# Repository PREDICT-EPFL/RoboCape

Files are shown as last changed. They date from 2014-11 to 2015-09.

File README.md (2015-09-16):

# RoboCape

This repository is dedicated to a Beaglebone cape extension developped at EPFL in the Automatic Control Laboratory.
The idea of this platform is to allow the user to transform any mechanically actuated platform, for example a RC car or a quadcopter base, into a robotic vehicle that can be controlled by a remote server.

The repository contains all the design files of the Beaglebone cape extension.
* Schematic
* PCB layout
* Production files
* Documentation files (useful documents and datasheets)

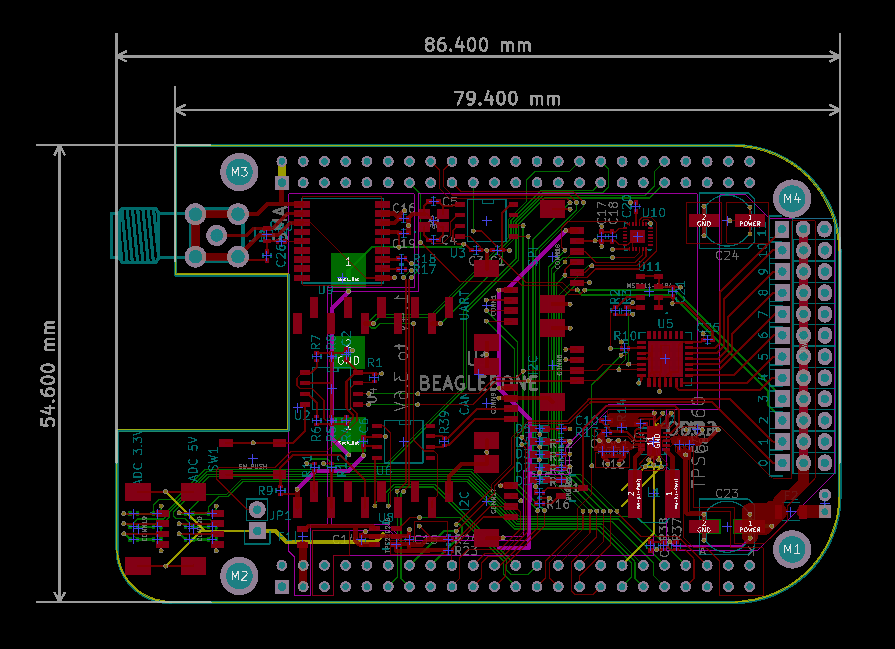
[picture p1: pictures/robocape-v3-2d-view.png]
Board Layout

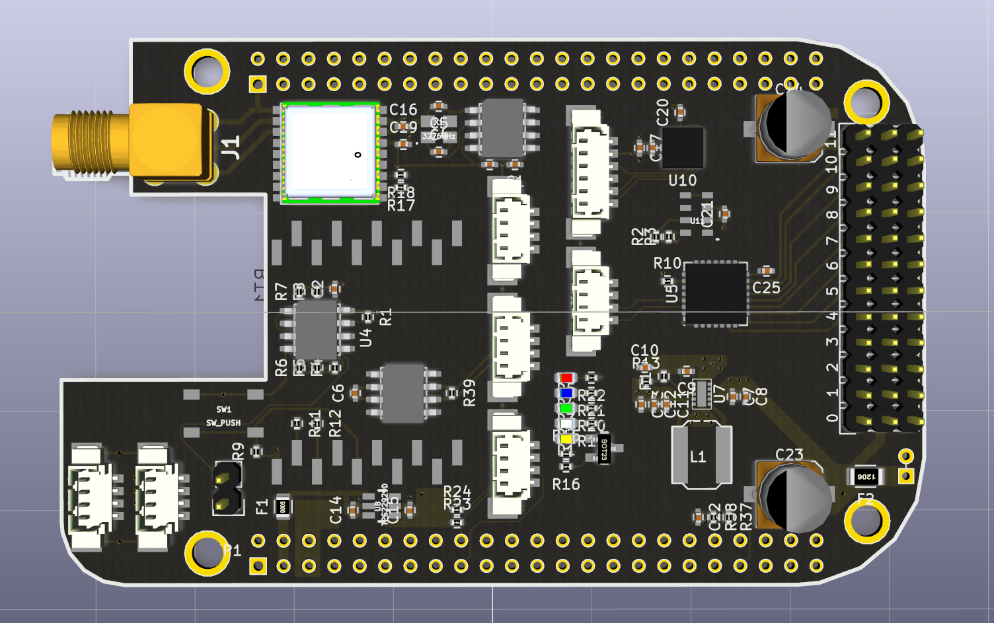
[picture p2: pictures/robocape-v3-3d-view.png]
Board 3D View


## Finished board

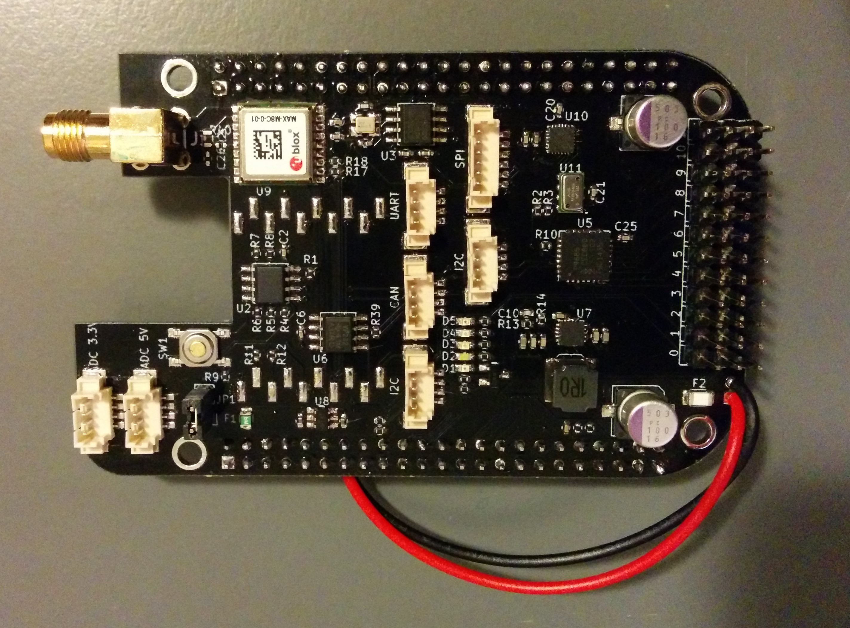
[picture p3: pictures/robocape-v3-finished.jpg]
Finished Board


## License


This project is released under the Creative Commons CC-BY-4.0 license.
See http://creativecommons.org/licenses/by/4.0/ for details.

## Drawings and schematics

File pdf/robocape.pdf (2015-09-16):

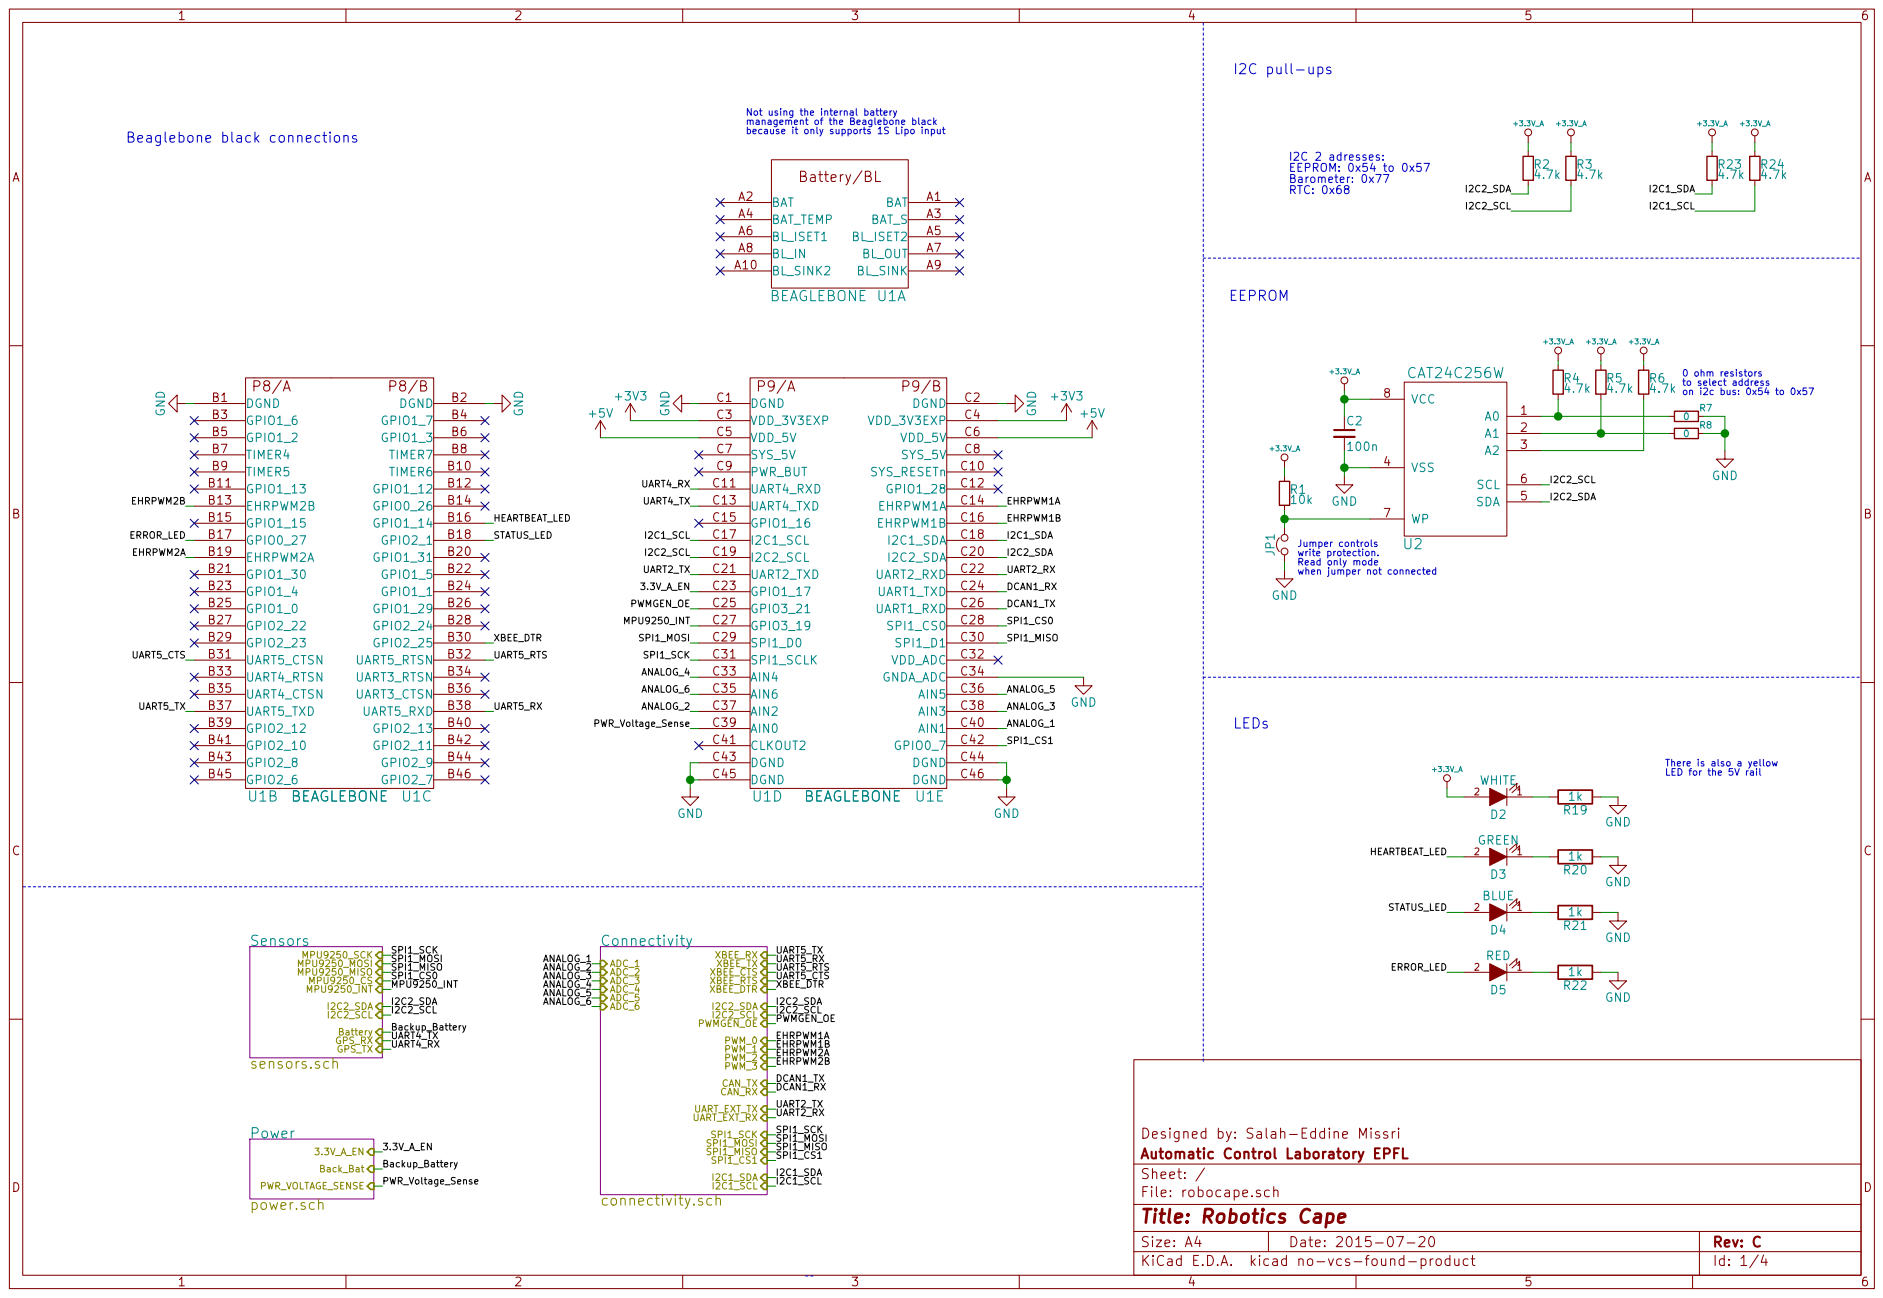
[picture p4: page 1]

0 ohm resistors
to select address on i2c bus: 0x54 to 0x57

Designed by: Salah-Eddine Missri
File: robocape.sch Sheet: / Automatic Control Laboratory EPFL

Id: 1/4 Title: Robotics Cape

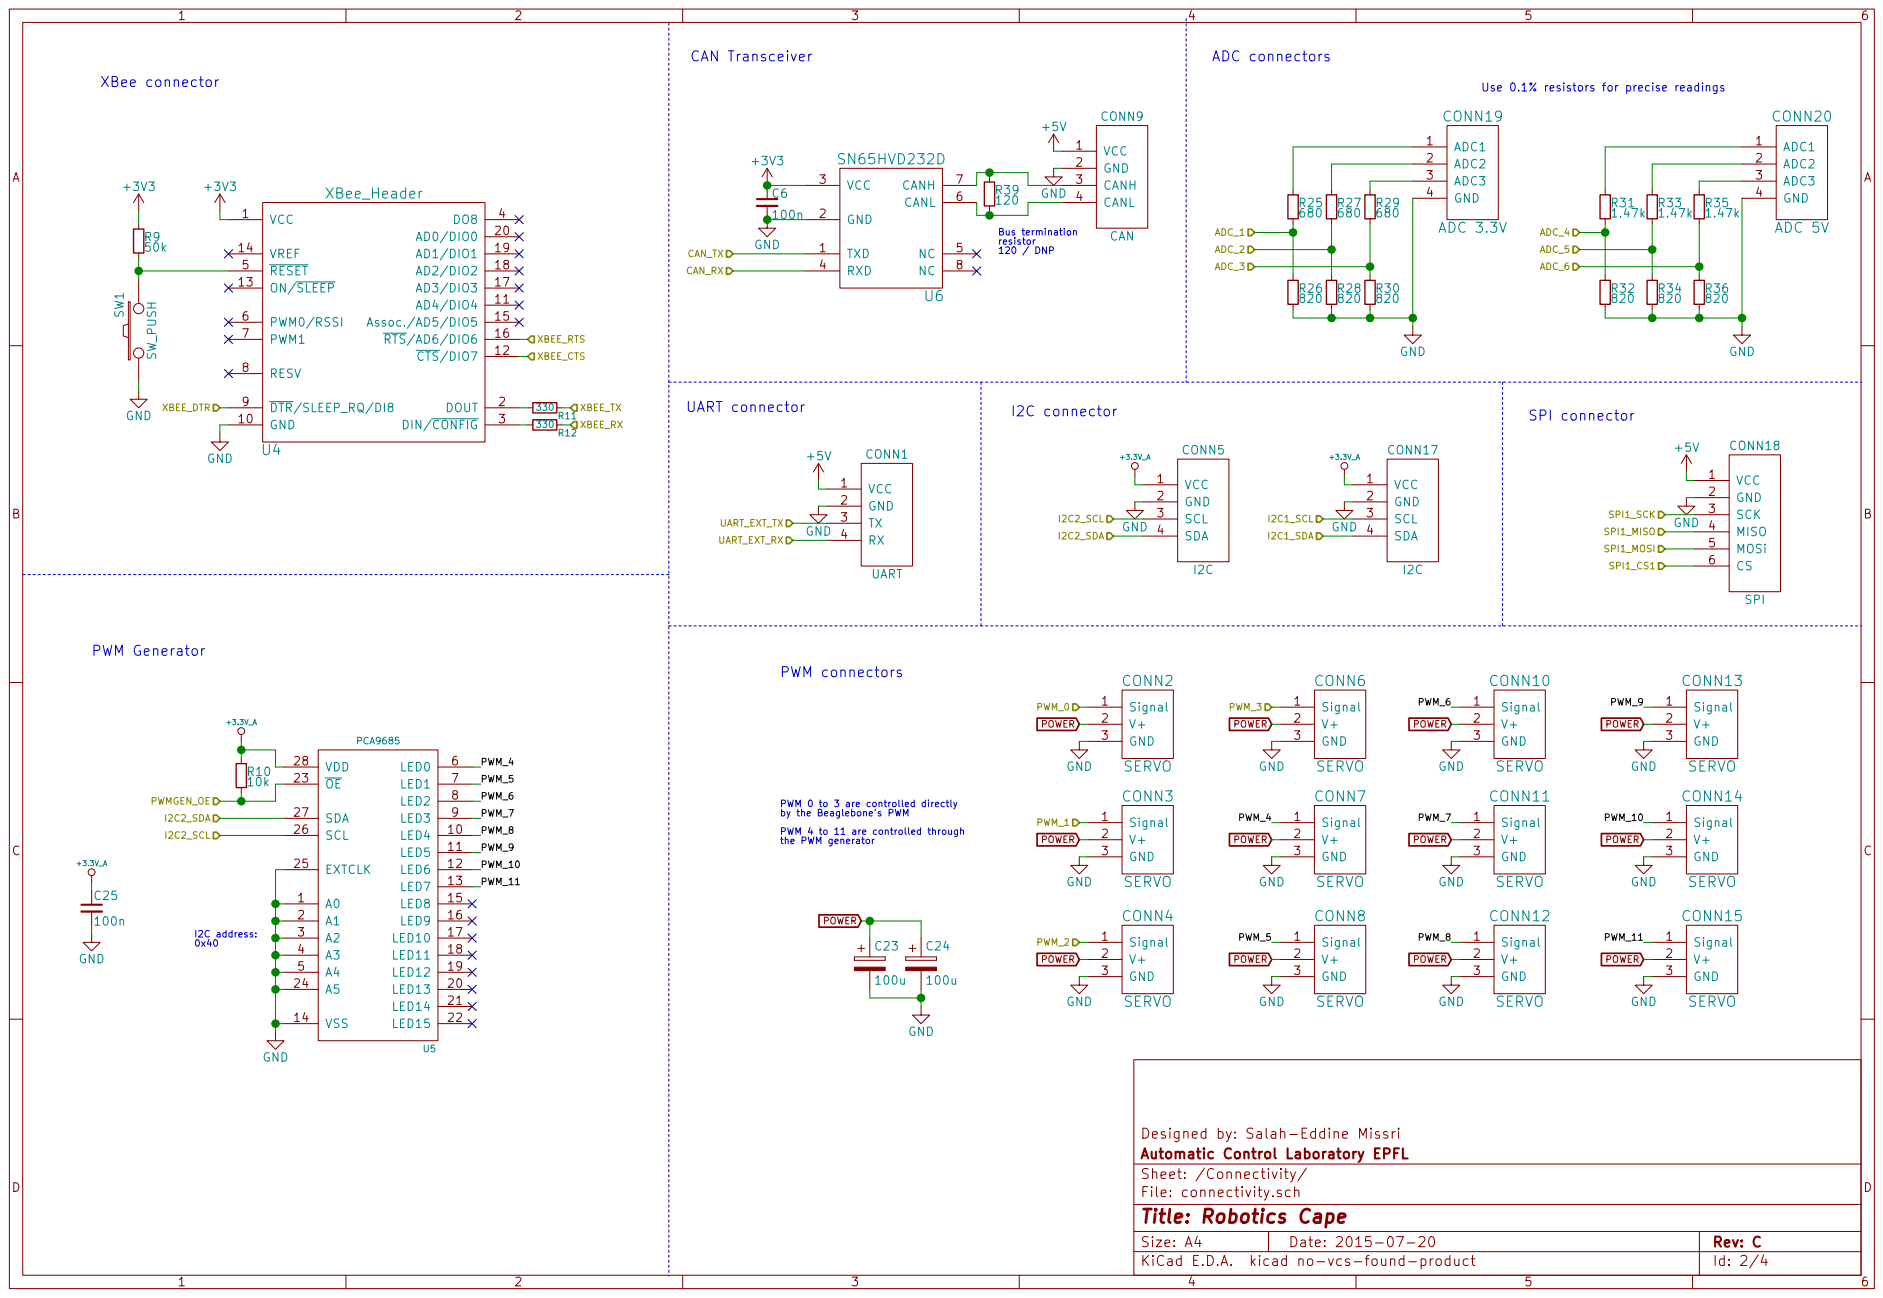
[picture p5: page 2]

1.47k Use 0.1% resistors for precise readings C23

Bus termination resistor 120 / DNP C25

PWM 0 to 3 are controlled directly by the Beaglebone's PWM

PWM 4 to 11 are controlled through

Designed by: Salah-Eddine Missri
Automatic Control Laboratory EPFL
Sheet: /Connectivity/
File: connectivity.sch
Id: 2/4 Title: Robotics Cape

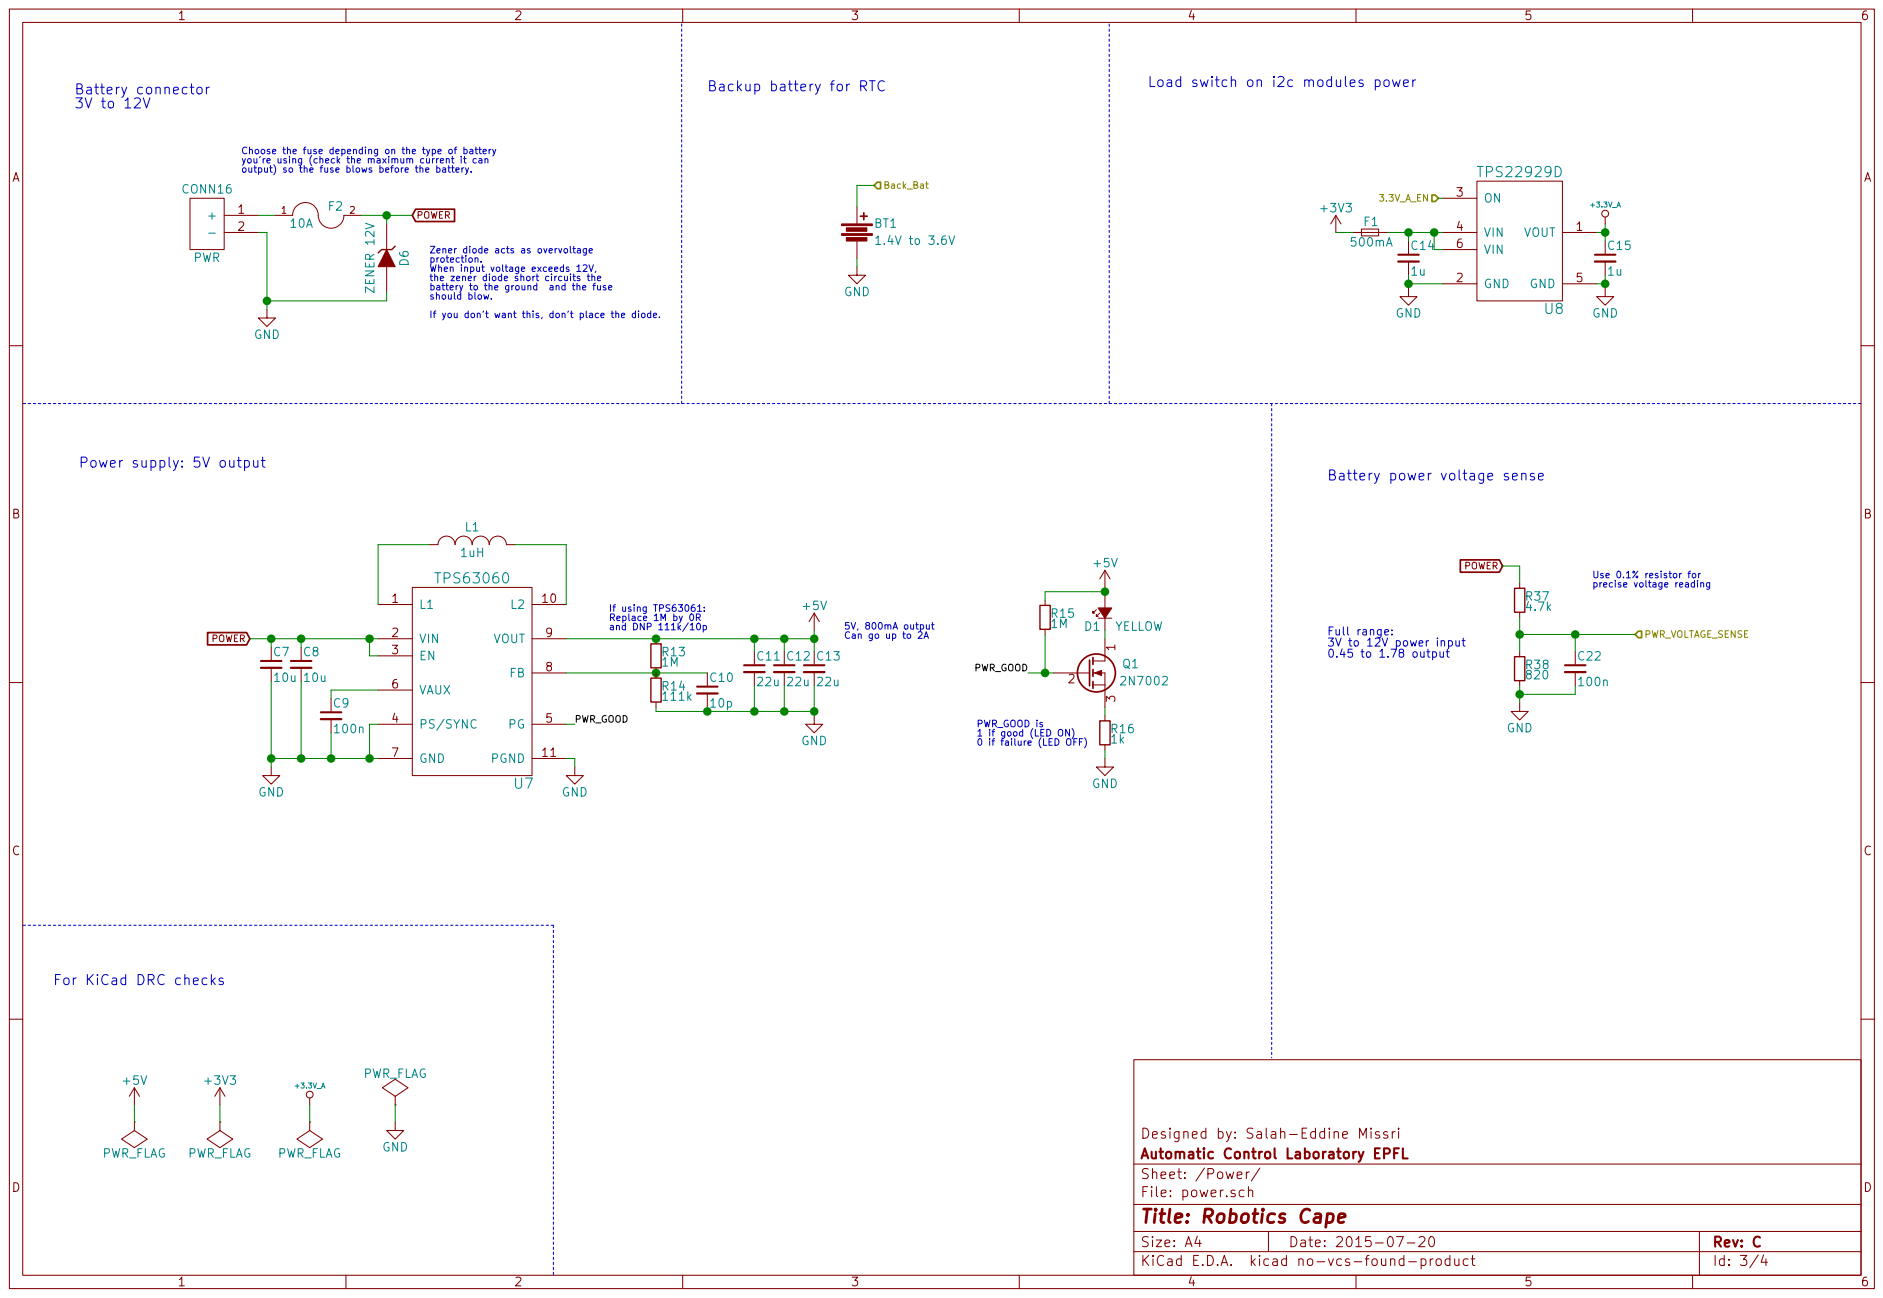
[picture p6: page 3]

Back_Bat Backup battery for RTC

Load switch on i2c modules power

If you don't want this, don't place the diode. Choose the fuse depending on the type of battery you're using (check the maximum current it can output) so the fuse blows before the battery.

the zener diode short circuits the battery to the ground and the fuse should blow.

Use 0.1% resistor for precise voltage reading Full range: 3V to 12V power input 0.45 to 1.78 output

If using TPS63061: Replace 1M by 0R

PWR_GOOD is 1 if good (LED ON) 0 if failure (LED OFF)

Designed by: Salah-Eddine Missri
File: power.sch Sheet: /Power/ Automatic Control Laboratory EPFL

Id: 3/4 Title: Robotics Cape

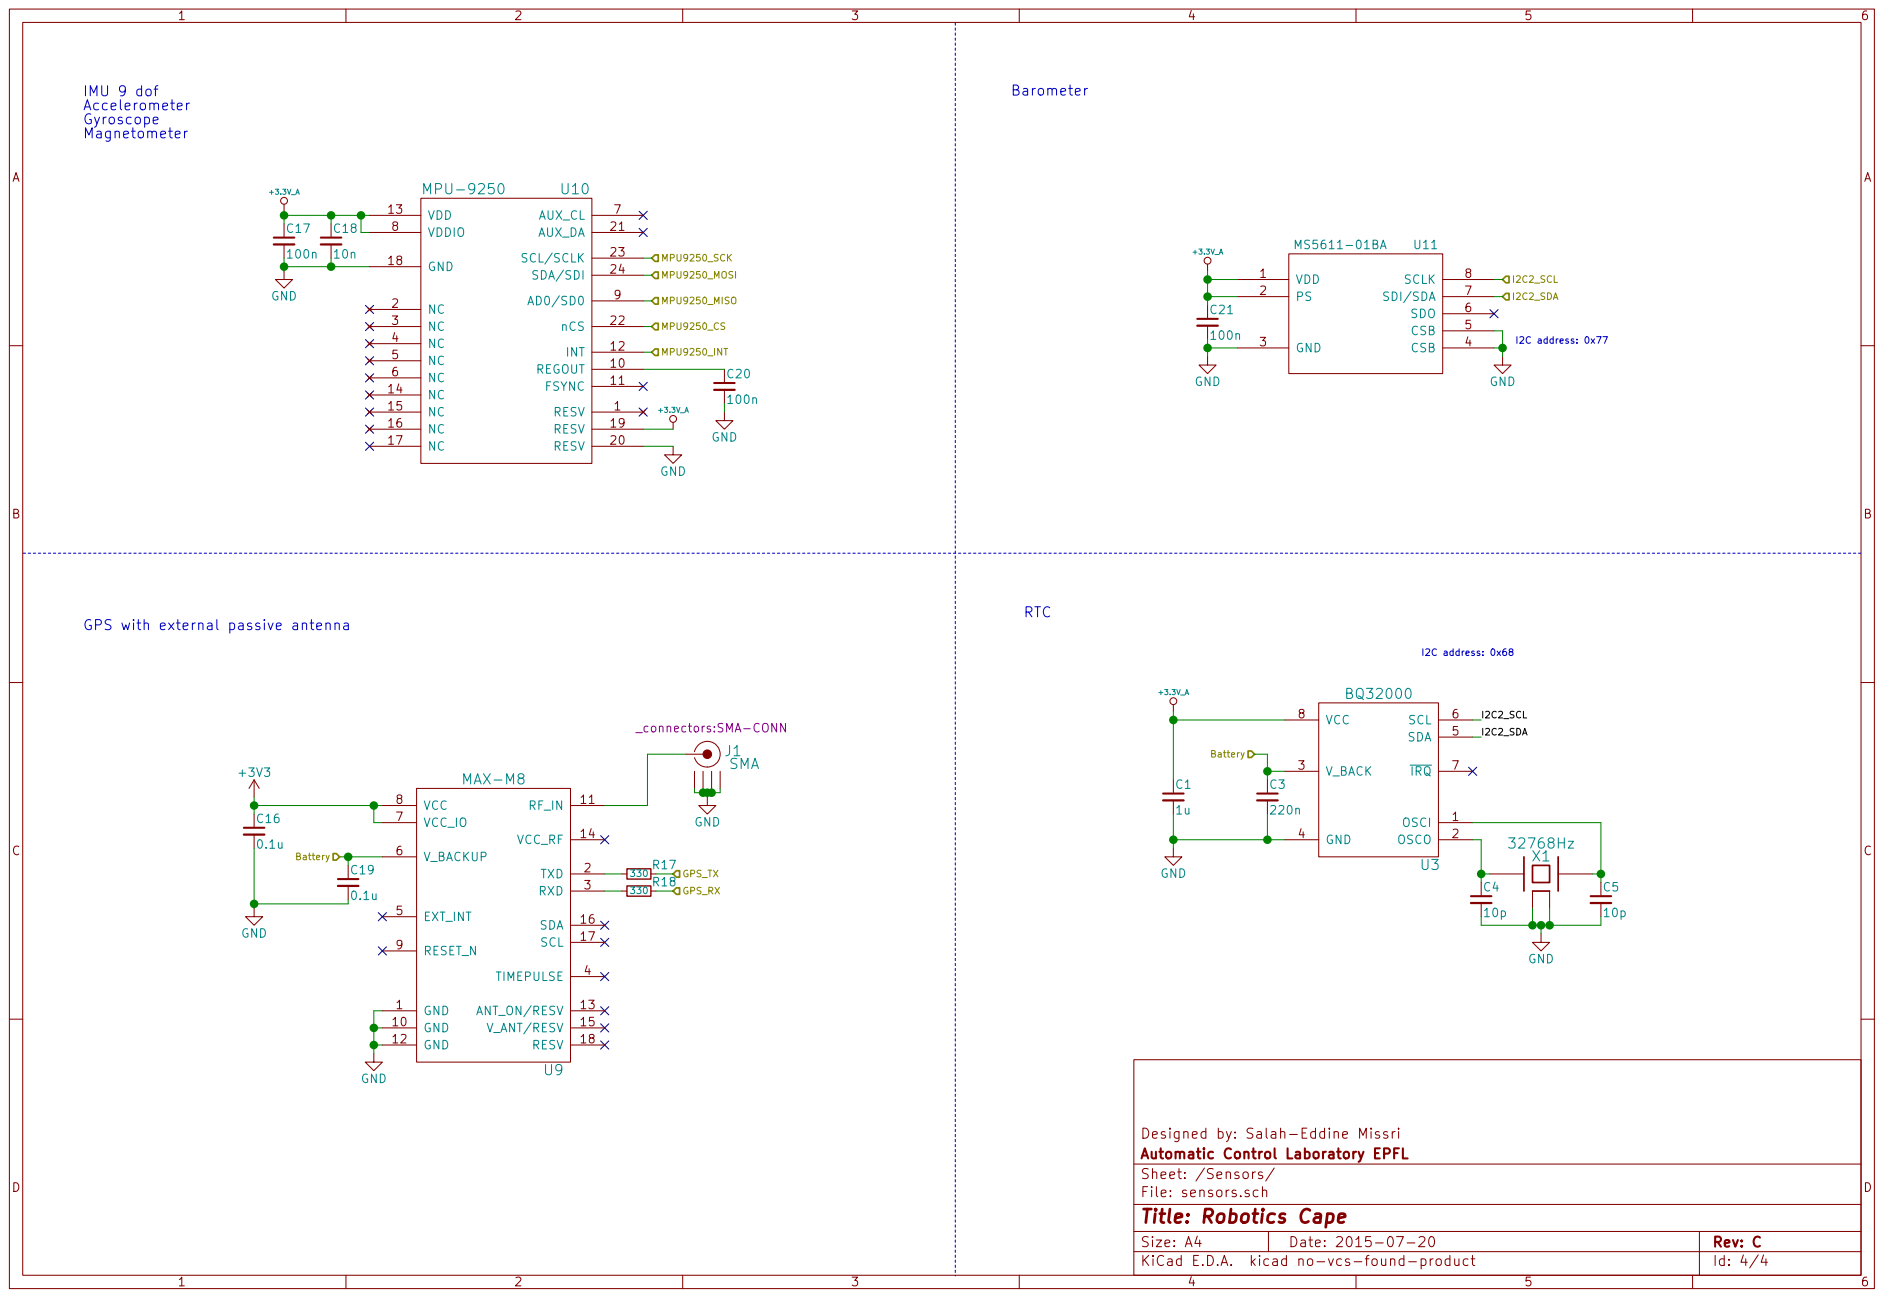
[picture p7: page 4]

IMU 9 dof Accelerometer Gyroscope

Designed by: Salah-Eddine Missri
File: sensors.sch Sheet: /Sensors/ Automatic Control Laboratory EPFL

Id: 4/4 Title: Robotics Cape

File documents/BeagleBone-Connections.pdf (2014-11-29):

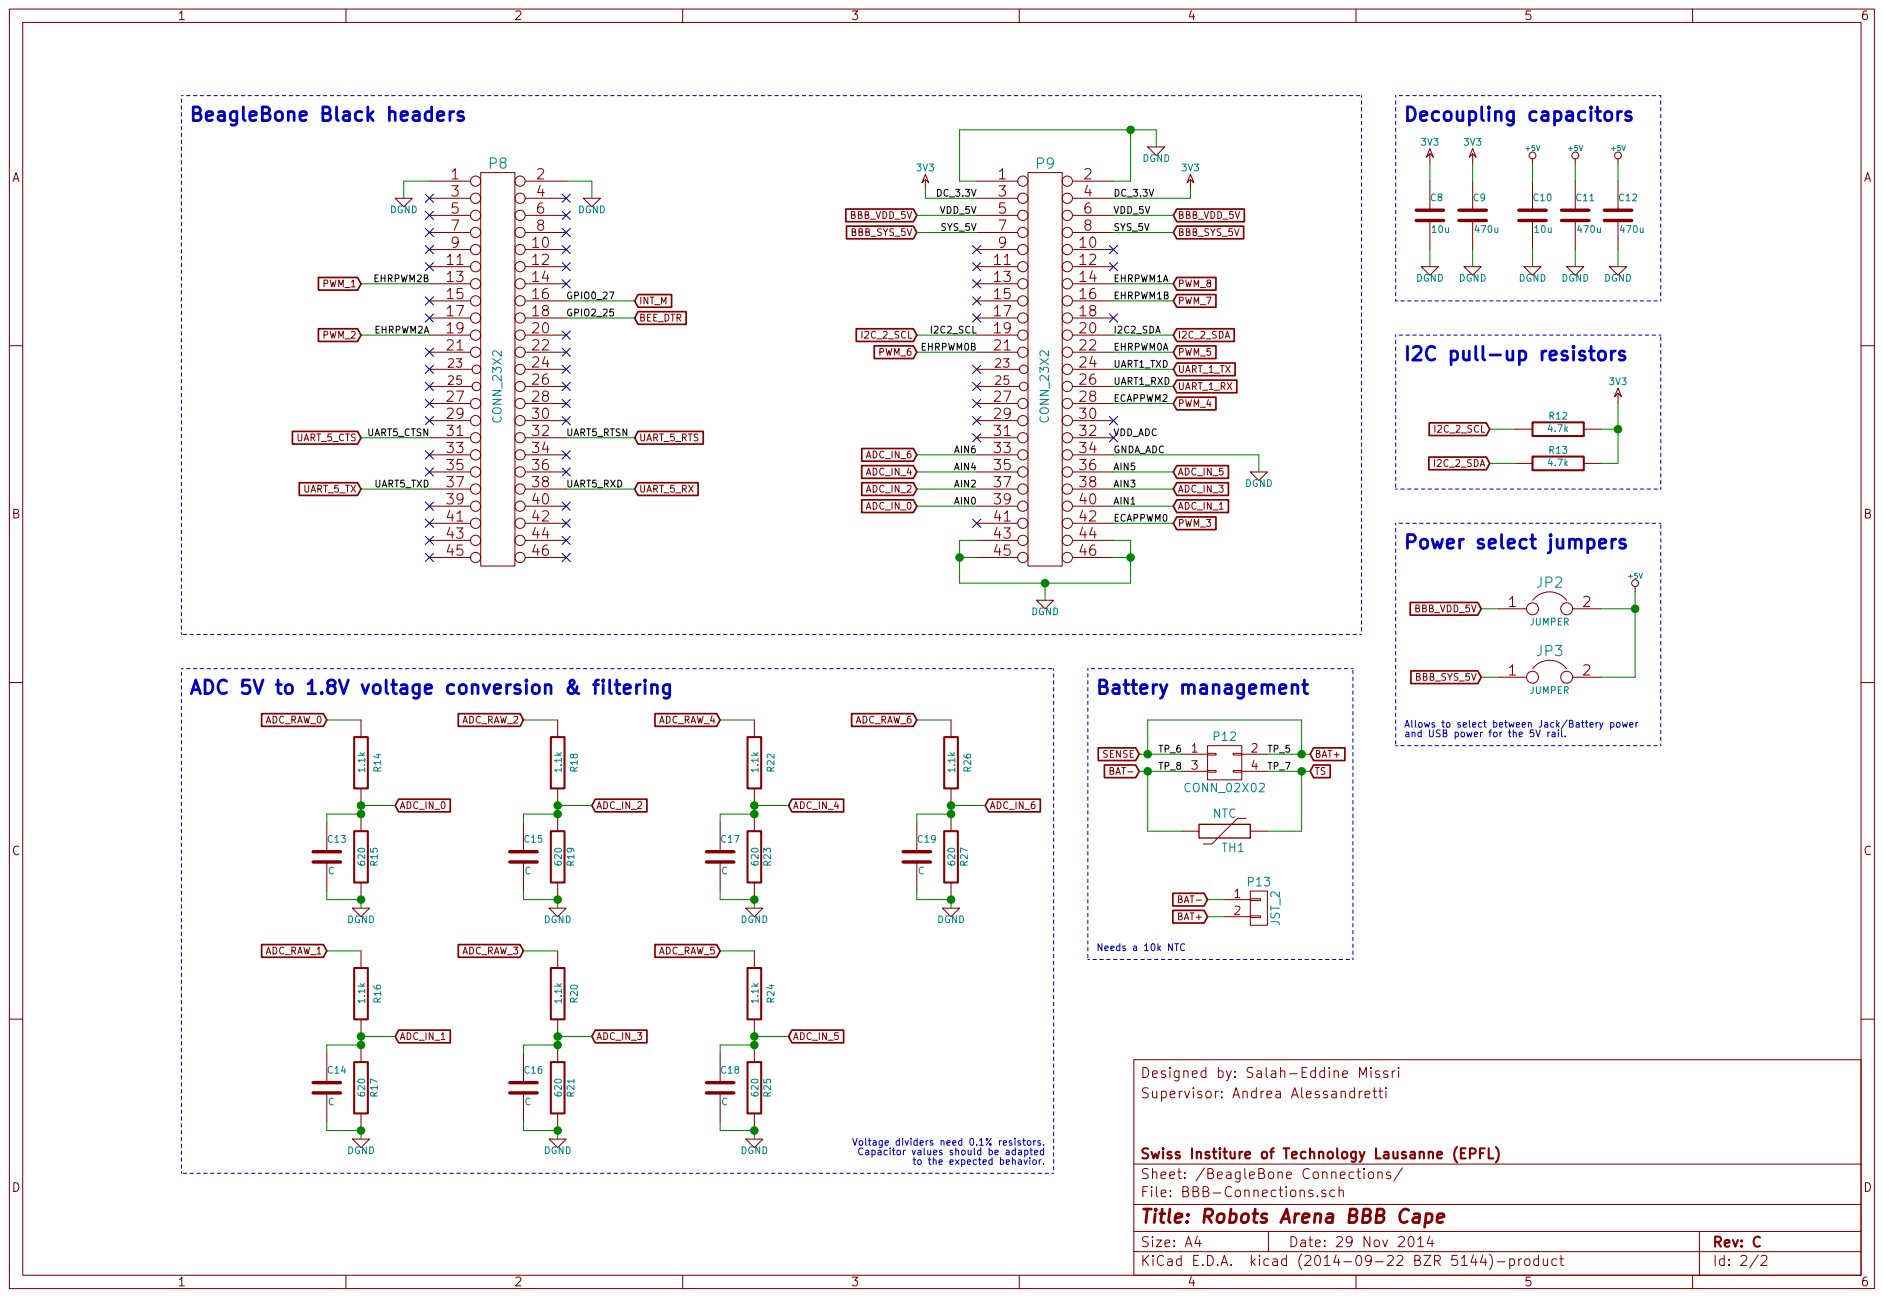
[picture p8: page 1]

JUMPER Power select jumpers

ADC_IN_5 ADC 5V to 1.8V voltage conversion & filtering

Designed by: Salah-Eddine Missri
Supervisor: Andrea Alessandretti

Voltage dividers need 0.1% resistors. Capacitor values should be adapted

Swiss Institure of Technology Lausanne (EPFL)
File: BBB-Connections.sch Sheet: /BeagleBone Connections/
Id: 2/2 Title: Robots Arena BBB Cape

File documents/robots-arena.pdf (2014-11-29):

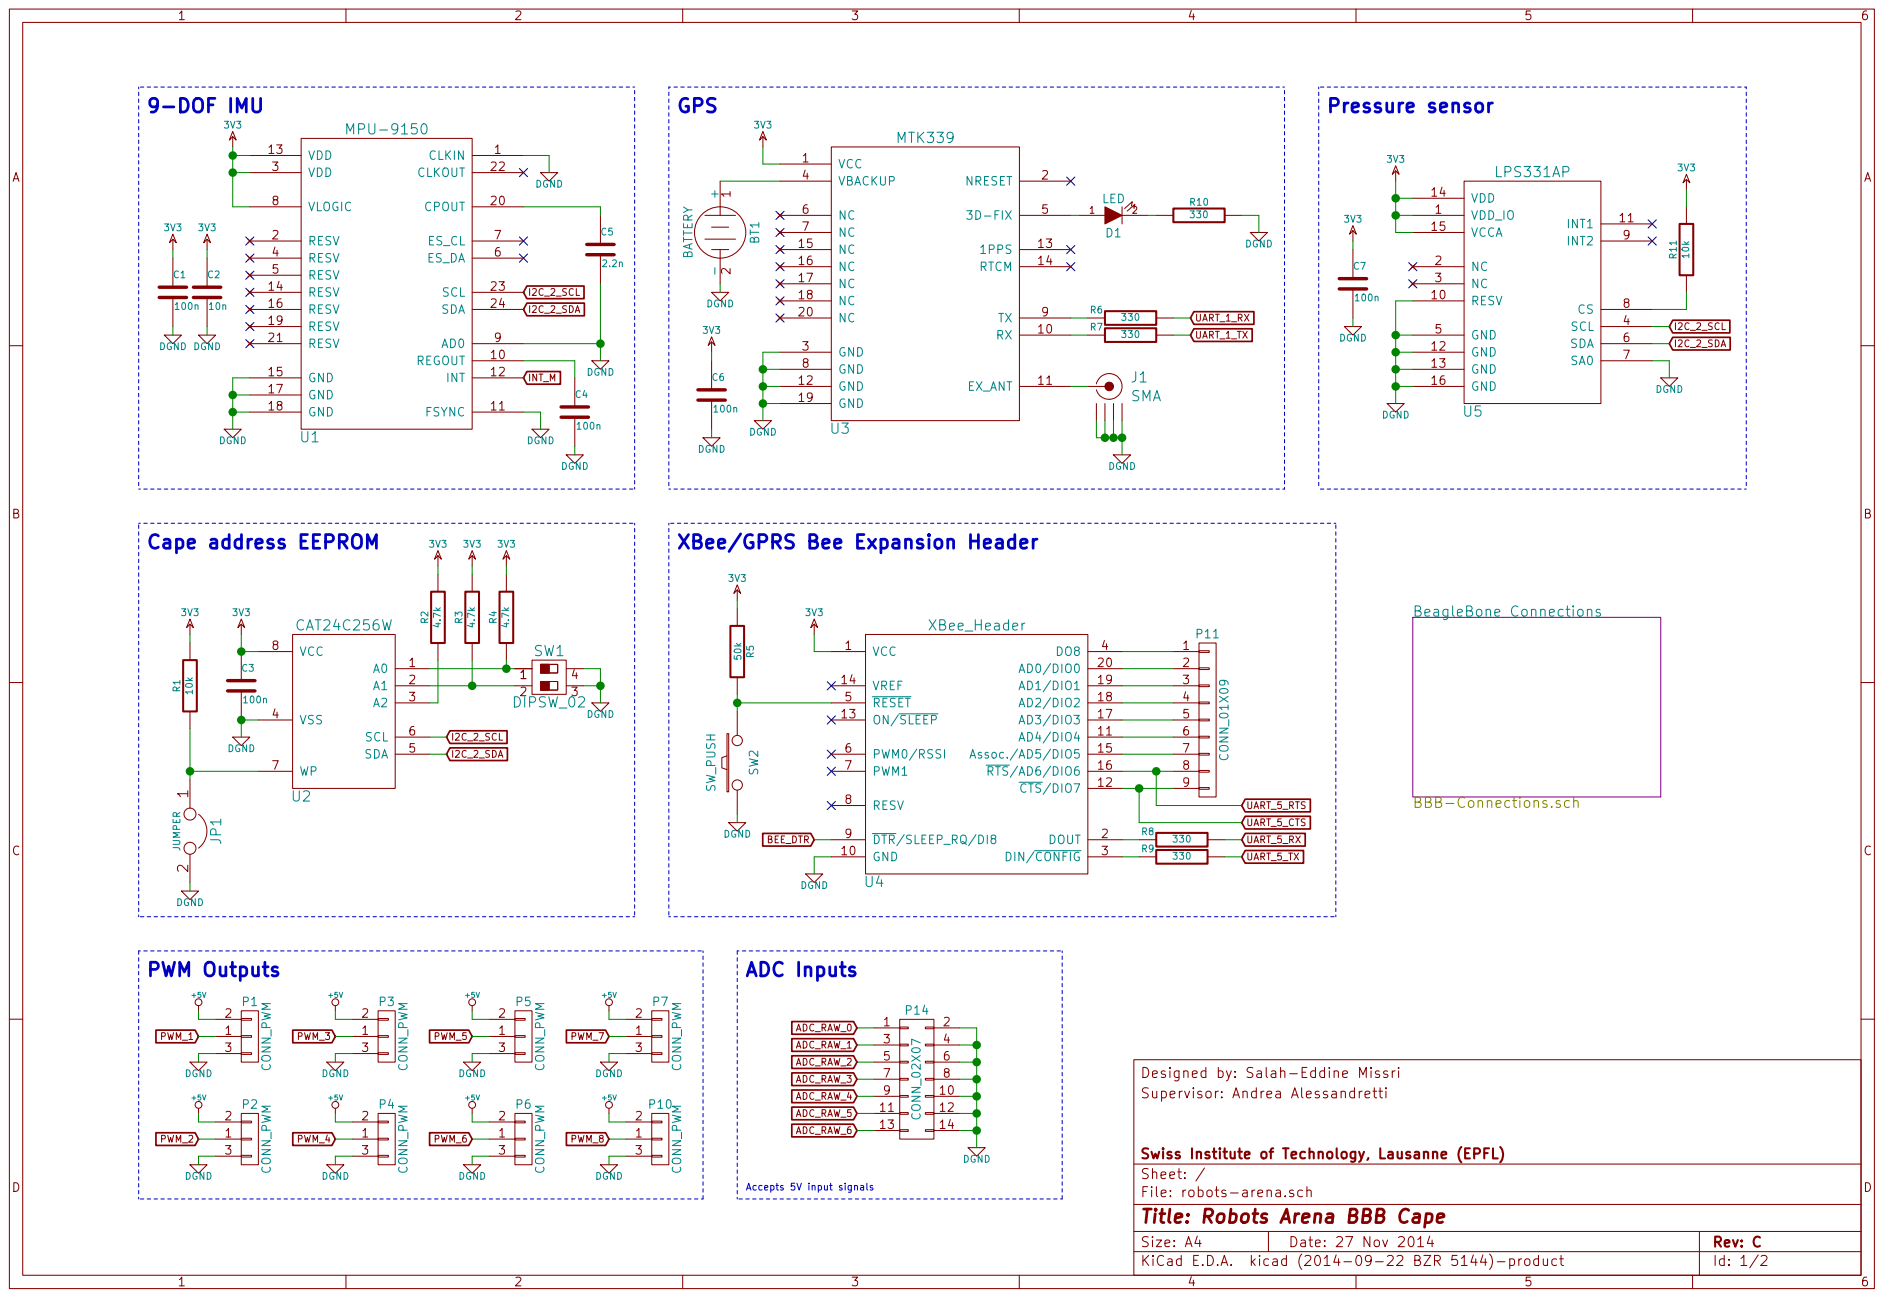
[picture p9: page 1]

9 P11 CONN_01X09 5 | UART_5_CTS UART_5_RTS UART_5_TX UART_5_RX R8

File: robots-arena.sch Sheet: / Swiss Institute of Technology, Lausanne (EPFL)

Id: 1/2 Title: Robots Arena BBB Cape

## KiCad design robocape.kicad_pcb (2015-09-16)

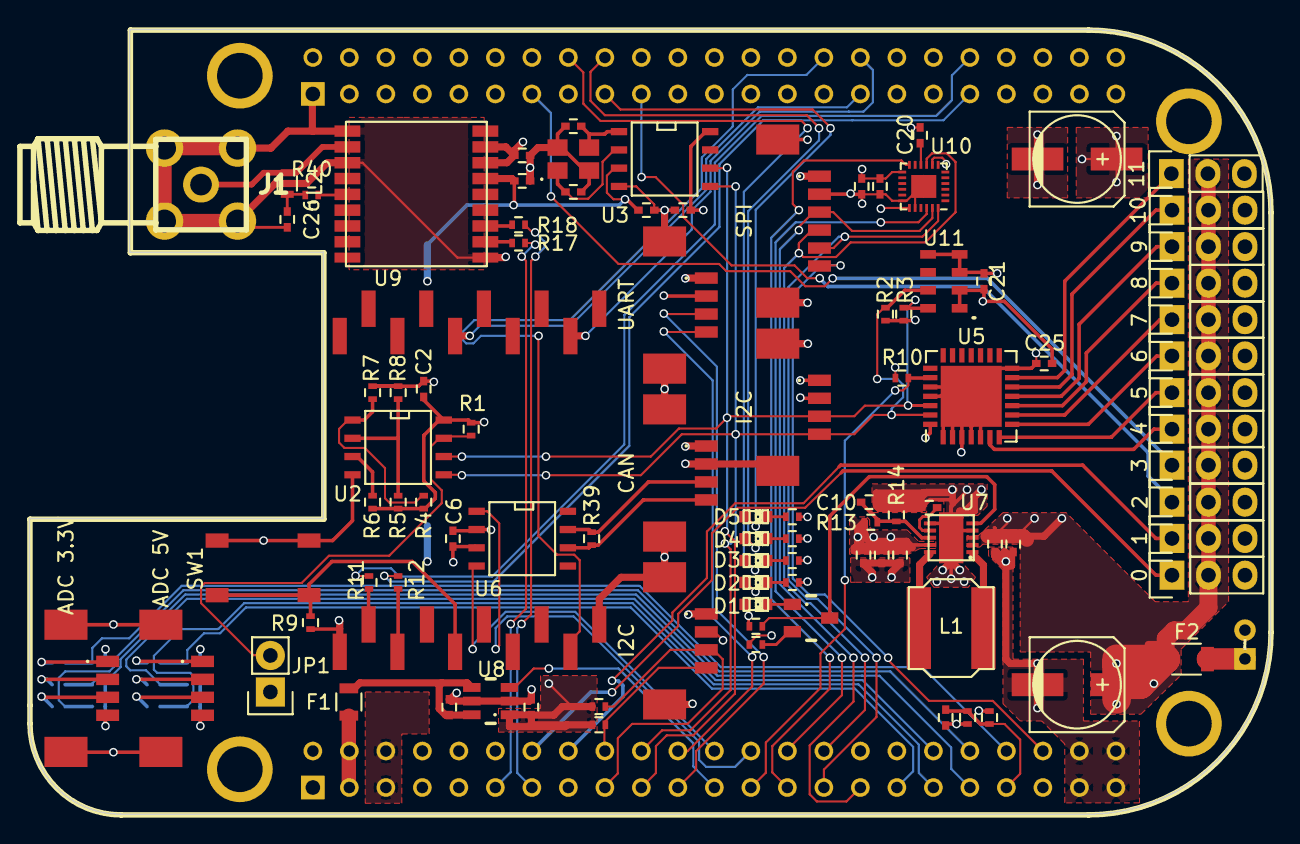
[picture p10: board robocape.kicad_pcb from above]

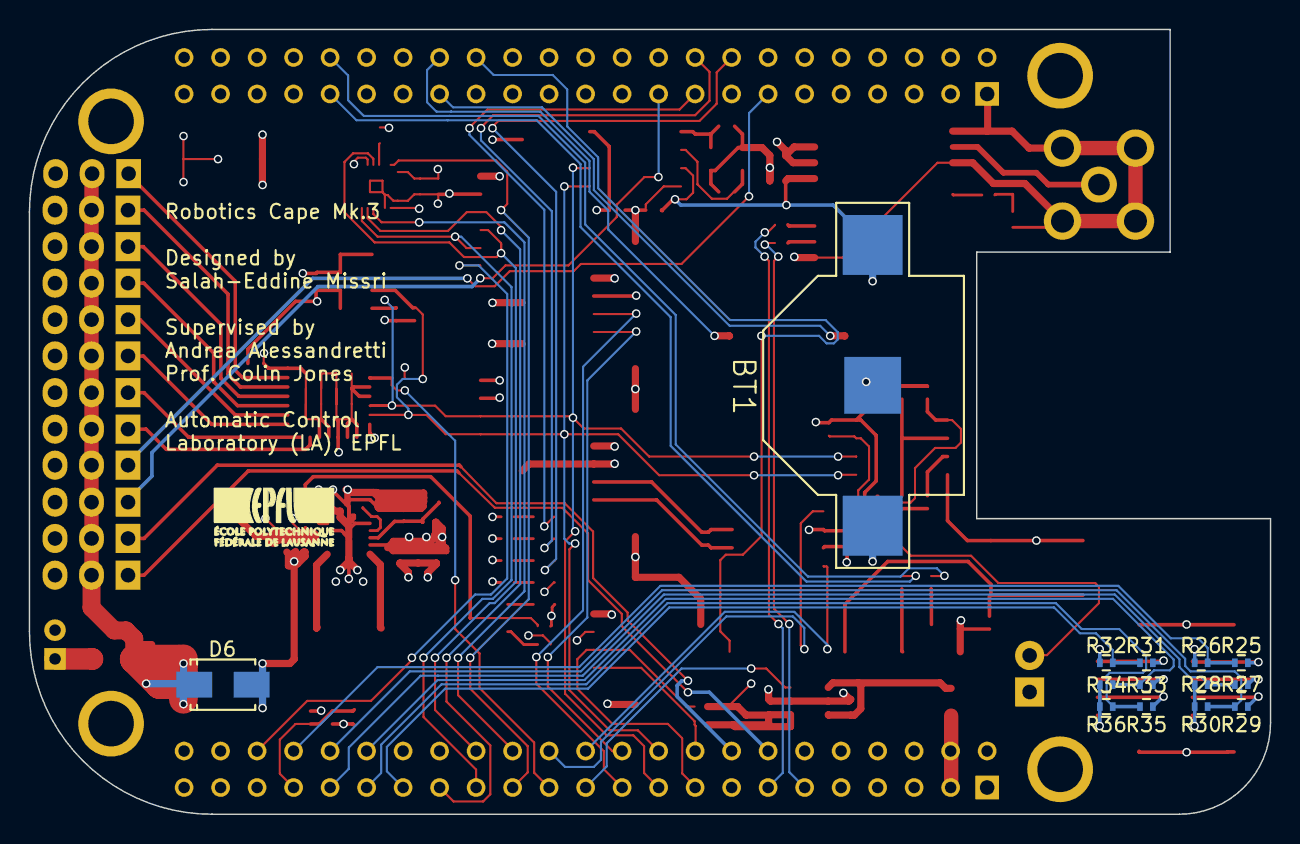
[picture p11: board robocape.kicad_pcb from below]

Board: 4 copper layers, 86.4 x 54.6 mm, 113 parts (14 on the bottom side), 87 nets.

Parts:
0, 1, 2, 3, 4, 5, 6, 7, 8, 9, 10, 11: SERVO; Pin_Header_Straight_1x03
BT1: 1.4V to 3.6V; BK-885
C1, C14, C15: 1u; C_0402
C2, C6, C9, C17, C20, C21, C22, C25: 100n; C_0402
C3: 220n; C_0402
C4, C5, C10: 10p; C_0402
C7, C8: 10u; C_0402
C11, C12, C13: 22u; C_0402
C16, C19: 0.1u; C_0402
C18: 10n; C_0402
C23, C24: 100u; c_elec_6.3x7.7
C26: C; C_0402
CONN1: UART; _Molex-PicoBlade-SMD-4
CONN5, CONN17: I2C; _Molex-PicoBlade-SMD-4
CONN9: CAN; _Molex-PicoBlade-SMD-4
CONN16: PWR; _Pin2mm_2
CONN18: SPI; _Molex-PicoBlade-SMD-6
CONN19: ADC 3.3V; _Molex-PicoBlade-SMD-4
CONN20: ADC 5V; _Molex-PicoBlade-SMD-4
D1: YELLOW; LED-0603
D2: WHITE; LED-0603
D3: GREEN; LED-0603
D4: BLUE; LED-0603
D5: RED; LED-0603
D6: ZENER 12V; Diode-SMA_Standard
F1: 500mA; R_0805
F2: 10A; R_1206
J1: SMA; SMA-CONN
JP1: Jumper_NC_Small; Pin_Header_Straight_1x02
L1: 1uH; Laird_TYS6045
L2: L; R_0603
Q1: 2N7002; _SOT23-3
R1, R10: 10k; R_0402
R2, R3, R4, R5, R6, R23, R24, R37: 4.7k; R_0402
R7, R8: 0; R_0402
R9: 50k; R_0402
R11, R12, R17, R18: 330; R_0402
R13, R15: 1M; R_0402
R14: 111k; R_0402
R16, R19, R20, R21, R22: 1k; R_0402
R25, R27, R29: 680; R_0402
R26, R28, R30, R32, R34, R36, R38: 820; R_0402
R31, R33, R35: 1.47k; R_0402
R39: 120; R_0402
R40: 10; R_0402
SW1: SW_PUSH; _PTS525SK15-SMT-Pushbutton
U1: BEAGLEBONE
U2: CAT24C256W; SOIC-8-N
U3: BQ32000; SOIC-8-N
U4: XBee_Header; Xbee_Header_SMD
U5: PCA9685; QFN-28-1EP_6x6mm_Pitch0.65mm
U6: SN65HVD232D; SOIC-8-N
U7: TPS63060; SON-10
U8: TPS22929D; _TSOT23-6
U9: MAX-M8
U10: MPU-9250; QFN-24-1EP_3x3mm_Pitch0.4mm
U11: MS5611-01BA; _MS5611-01BA
X1: 32768Hz; _TSX-3225-SMD-XTAL

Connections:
+3.3V_A: C1.1, C2.1, C15.1, C17.1, C18.1, C21.1, C25.1, CONN5.1, CONN17.1, D2.2, R1.1, R2.1, R3.1, R4.1, R5.1, R6.1, R10.1, R23.1, R24.1, U2.8, U3.8, U5.28, U8.1, U10.8, U10.13, U10.19, U11.1, U11.2
+3V3: C6.1, C16.1, F1.1, R9.1, U1.C3, U1.C4, U4.1, U6.3, U9.7, U9.8
+5V: C11.1, C12.1, C13.1, CONN1.1, CONN9.1, CONN18.1, D1.2, R13.1, R15.1, U1.C5, U1.C6, U7.9
/Connectivity/ADC_1: R25.2, R26.1, U1.C40
/Connectivity/ADC_2: R27.2, R28.1, U1.C37
/Connectivity/ADC_3: R29.2, R30.1, U1.C38
/Connectivity/ADC_4: R31.2, R32.1, U1.C33
/Connectivity/ADC_5: R33.2, R34.1, U1.C36
/Connectivity/ADC_6: R35.2, R36.1, U1.C35
/Connectivity/CAN_RX: U1.C24, U6.4
/Connectivity/CAN_TX: U1.C26, U6.1
/Connectivity/I2C1_SCL: CONN17.3, R24.2, U1.C17
/Connectivity/I2C1_SDA: CONN17.4, R23.2, U1.C18
/Connectivity/I2C2_SCL: CONN5.3, R3.2, U1.C19, U2.6, U3.6, U5.26, U11.8
/Connectivity/I2C2_SDA: CONN5.4, R2.2, U1.C20, U2.5, U3.5, U5.27, U11.7
/Connectivity/PWMGEN_OE: R10.2, U1.C25, U5.23
/Connectivity/PWM_0: 0.1, U1.C14
/Connectivity/PWM_1: 1.1, U1.C16
/Connectivity/PWM_2: 2.1, U1.B19
/Connectivity/PWM_3: 3.1, U1.B13
/Connectivity/PWM_4: 4.1, U5.6
/Connectivity/PWM_5: 5.1, U5.7
/Connectivity/PWM_6: 6.1, U5.8
/Connectivity/PWM_7: 7.1, U5.9
/Connectivity/PWM_8: 8.1, U5.10
/Connectivity/PWM_9: 9.1, U5.11
/Connectivity/PWM_10: 10.1, U5.12
/Connectivity/PWM_11: 11.1, U5.13
/Connectivity/SPI1_CS1: CONN18.6, U1.C42
/Connectivity/UART_EXT_RX: CONN1.4, U1.C22
/Connectivity/UART_EXT_TX: CONN1.3, U1.C21
/Connectivity/XBEE_CTS: U1.B32, U4.12
/Connectivity/XBEE_DTR: U1.B30, U4.9
/Connectivity/XBEE_RTS: U1.B31, U4.16
/Connectivity/XBEE_RX: R12.1, U1.B37
/Connectivity/XBEE_TX: R11.1, U1.B38
/ERROR_LED: D5.2, U1.B17
/HEARTBEAT_LED: D3.2, U1.B16
/Power/3.3V_A_EN: U1.C23, U8.3
/Power/Back_Bat: BT1.1, C3.1, C19.1, U3.3, U9.6
/Power/PWR_GOOD: Q1.2, R15.2, U7.5
/Power/PWR_VOLTAGE_SENSE: C22.1, R37.2, R38.1, U1.C39
/STATUS_LED: D4.2, U1.B18
/Sensors/GPS_RX: R18.1, U1.C13
/Sensors/GPS_TX: R17.1, U1.C11
/Sensors/MPU9250_CS: U1.C28, U10.22
/Sensors/MPU9250_INT: U1.C27, U10.12
/Sensors/MPU9250_MISO: CONN18.4, U1.C30, U10.9
/Sensors/MPU9250_MOSI: CONN18.5, U1.C29, U10.24
/Sensors/MPU9250_SCK: CONN18.3, U1.C31, U10.23
GND: 0.3, 1.3, 2.3, 3.3, 4.3, 5.3, 6.3, 7.3, 8.3, 9.3, 10.3, 11.3, BT1.2, C1.2, C2.2, C3.2, C4.2, C5.2, C6.2, C7.2, C8.2, C9.2, C10.2, C11.2, C12.2, C13.2, C14.2, C15.2, C16.2, C17.2, C18.2, C19.2, C20.2, C21.2, C22.2, C23.2, C24.2, C25.2, C26.2, CONN1.2, CONN1.MECH, CONN5.2, CONN5.MECH, CONN9.2, CONN9.MECH, CONN16.2, CONN17.2, CONN17.MECH, CONN18.2, CONN18.MECH, CONN19.4, CONN19.MECH, CONN20.4, CONN20.MECH, D6.2, J1.2, J1.3, J1.4, J1.5, JP1.1, R7.2, R8.2, R14.2, R16.2, R19.1, R20.1, R21.1, R22.1, R26.2, R28.2, R30.2, R32.2, R34.2, R36.2, R38.2, SW1.1, U1.B1, U1.B2, U1.C1, U1.C2, U1.C34, U1.C43, U1.C44, U1.C45, U1.C46, U2.4, U3.4, U4.10, U5.1, U5.2, U5.3, U5.4, U5.5, U5.14, U5.24, U5.25, U5.29, U6.2, U7.4, U7.7, U7.11, U8.2, U8.5, U9.1, U9.10, U9.12, U10.18, U10.20, U10.25, U11.3, U11.4, U11.5, X1.2, X1.4
unnamed: C4.1, U3.2, X1.1
unnamed: C5.1, U3.1, X1.3
unnamed: C9.1, U7.6
unnamed: C10.1, R13.2, R14.1, U7.8
unnamed: C14.1, F1.2, U8.4, U8.6
unnamed: C20.1, U10.10
unnamed: C26.1, L2.2, R40.1
unnamed: CONN9.3, R39.1, U6.7
unnamed: CONN9.4, R39.2, U6.6
unnamed: CONN16.1, F2.1
unnamed: CONN19.1, R25.1
unnamed: CONN19.2, R27.1
unnamed: CONN19.3, R29.1
unnamed: CONN20.1, R31.1
unnamed: CONN20.2, R33.1
unnamed: CONN20.3, R35.1
unnamed: D1.1, Q1.1
unnamed: D2.1, R19.2
unnamed: D3.1, R20.2
unnamed: D4.1, R21.2
unnamed: D5.1, R22.2
unnamed: J1.1, L2.1, U9.11
unnamed: JP1.2, R1.2, U2.7
unnamed: L1.1, U7.1
unnamed: L1.2, U7.10
unnamed: Q1.3, R16.1
unnamed: R4.2, R7.1, U2.1
unnamed: R5.2, R8.1, U2.2
unnamed: R6.2, U2.3
unnamed: R9.2, SW1.2, U4.5
unnamed: R11.2, U4.2
unnamed: R12.2, U4.3
unnamed: R17.2, U9.2
unnamed: R18.2, U9.3
unnamed: R40.2, U9.14
POWER: 0.2, 1.2, 2.2, 3.2, 4.2, 5.2, 6.2, 7.2, 8.2, 9.2, 10.2, 11.2, C7.1, C8.1, C23.1, C24.1, D6.1, F2.2, R37.1, U7.2, U7.3

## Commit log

2014-11-10 v0.1 of the cape, tested and working
    [BOM_v0.1.xlsx, RA-BBB-Connections.sch, RA-BackupConns.sch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]
2014-11-22 organisation restructuration
    [BOM_v0.1.xlsx, RA-BBB-Connections.sch, RA-BackupConns.sch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]
2014-11-23 restructuration of components & schematic
    [BBB-Connections.sch, RA-BBB-Connections.sch, RA-BackupConns.sch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]
2014-11-24 added bat mgmt, pwr select, xbee header
    [BBB-Connections.sch, robots-arena.sch]
2014-11-25 .sch done, .net done, components on PCB done
    [BBB-Connections.sch, robots-arena.kicad_pcb, robots-arena.sch]
2014-11-25 layout in progress, corrected pwm order
    [BBB-Connections.sch, robots-arena.kicad_pcb]
2014-11-29 Added adc connectors w/ 5 to 1.8V conversion
    [BBB-Connections.sch, robots-arena.kicad_pcb, robots-arena.sch]
2014-11-29 Added comments on the schematics
    [BBB-Connections.sch, robots-arena.sch]
2014-11-29 Update netlist & components footprints
    [BBB-Connections.sch, robots-arena.kicad_pcb, robots-arena.sch]
2014-11-29 Place components on PCB & ajust nets to stay w/ 2 layers
    [BBB-Connections.sch, robots-arena.kicad_pcb, robots-arena.sch]
2014-11-29 Layout completed
    [robots-arena.kicad_pcb]
2014-11-29 Gerber files generated
    [robots-arena-B_Cu.gbl, robots-arena-B_Mask.gbs, robots-arena-B_SilkS.gbo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]
2014-12-25 Correct XBee header & Update layout and Gerber files
    [robots-arena-B_Cu.gbl, robots-arena-B_Mask.gbs, robots-arena-B_SilkS.gbo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]
2015-01-02 Add BOM with Digikey links & price calculation
    [robot-arena-bom.xls]
2015-07-14 Add Kicad library as submodule
2015-07-14 Project initial setup
    [connectivity.sch, power.sch, robocape.sch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]
2015-07-14 Schematic: EEPROM + IMU
    [connectivity.sch, power.sch, robocape.sch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]
2015-07-14 Schematic: Barometer
    [robocape.sch, sensors.sch]
2015-07-15 Schematic: Xbee header
    [connectivity.sch, robocape.sch, sensors.sch]
2015-07-16 Schematics: PWM
    [connectivity.sch, robocape.sch]
2015-07-18 Schematics: CAN
    [connectivity.sch, robocape.sch]
2015-07-18 Schematics: Power supply from battery input
    [power.sch]
2015-07-20 Schematics: GPS, Backup battery & Load Switch
    [power.sch, robocape.sch, sensors.sch]
2015-07-20 Schematics: Additional connectors (ADC, I2C, UART)
    [connectivity.sch, robocape.sch]
2015-07-20 Schematics: RTC
    [connectivity.sch, robocape.sch]
2015-07-20 Schematics: Minor cleanups
    [connectivity.sch, power.sch, robocape.sch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]
2015-07-20 Schematics: LEDs
    [connectivity.sch, power.sch, robocape.sch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]
2015-07-20 Schematics: Additional I2C connector
    [connectivity.sch, power.sch, robocape.sch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]
2015-07-20 Schematics: Missing I2C1 pull-ups
    [connectivity.sch, power.sch, robocape.sch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]
2015-07-20 Schematics: SPI connector
    [connectivity.sch, power.sch, robocape.sch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]
2015-07-20 Schematics: Minor cleanups & ADC split between 3.3V & 5V
    [connectivity.sch, power.sch, robocape.sch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]
2015-07-20 Schematics: Power input overvoltage protection
    [connectivity.sch, power.sch, robocape.sch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]
2015-07-21 Schematics: CAN termination resistor + PWM gen decoupling cap
    [connectivity.sch, robocape.sch]
2015-07-21 PCB: Components placed
    [robocape.kicad_pcb]
2015-07-22 PCB: Layout of close tracks
    [connectivity.sch, power.sch, robocape.kicad_pcb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]
2015-07-22 PCB: 3v3 zone fill in power plane + 3v3 wiring
    [robocape.kicad_pcb]
2015-07-23 PCB: PWM silkscreen & some 3d models
    [robocape.kicad_pcb]
2015-07-23 PCB: Correct footprint and layout of 5V regulator
    Also added some 3D models (GPS, SMA)
    [connectivity.sch, power.sch, robocape.kicad_pcb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]
2015-07-23 PCB: More tracks
    [robocape.kicad_pcb]
2015-07-23 PCB: More and more tracks
    [connectivity.sch, robocape.kicad_pcb, sensors.sch]
2015-07-24 PCB: Done
    [robocape.kicad_pcb, sensors.sch]
2015-07-24 Schematics in pdf format
2015-07-24 Gerber production files
    [robocape-B_Cu.gbl, robocape-B_Mask.gbs, robocape-B_SilkS.gbo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]
2015-08-11 Correct GPS schematic/layout to account for active antenna
    [connectivity.sch, power.sch, robocape.kicad_pcb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]
2015-09-16 Add pictures in readme to show the board
